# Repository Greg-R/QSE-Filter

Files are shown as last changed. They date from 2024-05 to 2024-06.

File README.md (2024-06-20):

# QSE-Filter Version 1.0

This is the PCB for the QSE-Filter module for the T41 "Software Defined Transceiver".
The PCB was designed using the open-source design tool Kicad 8.

The primary documentation for the T41 is the book "Digital Signal Processing and Software Defined Radio:
Theory and Construction of the T41-EP Software Defined Transceiver" by Albert Peter and Jack Purdum.
The book is available here:

<https://www.amazon.com/Digital-Signal-Processing-Software-Defined/dp/B0D25FV48C>

The goal of the QSE-Filter is to improve T41 transmitter fidelity.  Without using
this filter, the transmit output will contain spurious energy.  Using this simple filter
will resolve this problem.  The QSE-Filter module is designed to be the simplest
and lowest cost circuit to resolve this specific spurious energy problem.

The QSE-Filter is inserted between the output of the QSE module and the input of the
Power Amplifier.

Gerber files for PCB fabrication are included in the gerbers folder.
A PDF of the schematic (QSE-Filter.pdf) is included for quick viewing of the circuit design.

A look at the schematic:

<https://github.com/Greg-R/QSE-Filter/blob/main/QSE-Filter.pdf>

## Video Illustration of the Spurious Problem

This video shows why it is necessary to have a filter on the output of the QSE:

<https://drive.google.com/file/d/18EVahQOBdGZIAjiurM7DPEM1uzlL1K75/view?usp=drive_link>

### Hardware Modifications

A new ribbon cable is required.  The original T41 has a 10-wire cable which connects the Main board module to the Low-Pass
Filter module.  Since the QSE-Filter shares the same control signals, a new ribbon cable is required which routes from the
Main board to the QSE-Filter, and then to the Low-Pass module.  This type of cable is very easy to build and can be
completed in five minutes or less.

A wire must be added to the Main board to supply 3.3 volts.  This wire should be soldered to the back side of the Main
board from pin 8 of the "Bands" connector to a convenient source of 3.3 volts.  Looking at my modified Main board:

<https://drive.google.com/file/d/1hGLFVzCbjHw2UNAi1ffdGSL7jEQ02EJ3/view?usp=drive_link>

The green wire in the upper right area of the Main board routes 3.3 volts to the QSE-Filter via the ribbon cable.

There is no modification required to the software.

### PCB Layout

The PCB layout was completed using Kicad version 8.  This is an open-source tool, unlike the "Dip Trace" commercial product used
to design the V010 and other T41 boards.

The prototype PCBs were fabricated by PCBWay at a cost of US$1.00 each.  Shipping was about US$25.00 for quantity 5 boards.

## Bill Of Material (BOM)

A public Digikey BOM is here:

<https://www.digikey.com/en/mylists/list/BP824NCB5P>

The toroids are not included in the above BOM.  The T-37-6 (quantity 6) and T-37-17 (quantity 4) may be ordered from:

<https://kitsandparts.com/>

## Build Tips

In general, QSE-Filter is easy to build if you have experience with surface-mount components.  There are a few items to be aware of
to avoid build errors.

### SOT Devices

This circuit uses a lot of SOT devices!  These are generally well behaved when using a hot-air soldering station.  Be careful to not
use too much solder on the pads.  I had one short-circuit underneath one of the switches which caused high filter loss.  A little
bit of probing with a DVM revealed the short, and once the short was cleared the circuit worked as expected.

### Toroids

This is what I consider the most difficult part of building the filter.  Toroid winding!
The toroid part numbers, wire gauge, and number of turns are shown on the schematic.

Try to space the windings evenly around the circumference of the toroid.  However, the will be a gap in the windings
at the wire ends.

The toroids are "surface mounted", meaning that there is a rectangular pad for soldering the wire end.  I find this much
easier to deal with than using through-holes, as soldering and re-soldering is much easier.  Why resoldering?  Because
it may be necessary to add or remove a turn to get the frequency response lined up just right.  Hopefully not, however,
there are tolerances associated with both the capacitors and the toroids.  The inductance will be a function of the toroid
permeability, the number of turns, and also how you wound it.  The frequency responses of the filters are designed to have
margin, so hopefully all will line up and the frequency response of the filters will achieve the goal of a clean transmit
spectrum.

I have recommended using AWG#28 for the 80, 40, and 20 meter coils, and AWG#27 for the 15 and 10 meter coils.
However, AWG#27 will probably work for all of the coils.  I have not tried this yet.

### 3D Printed Bracket

The QSE Filter uses a custom 3D printed bracket.  I have a repository with many files for T41 parts including the QSE Filter bracket:

<https://github.com/Greg-R/SDT_Case_KF5N>

### Bottom Side Parts

There are many parts on the bottom side.  These should be soldered after the top-side SMDs.  I was able to use a hot air gun without any of the top-side components desoldering.

Solder the 16 pin connector and the SMA connectors last.

### SMA Connectors

Take a good look at the placement of the board in your T41 radio.  You will want the SMA connectors of the QSE-Filter in the orientation for
easy coaxial cable routing.  0 or 90 degree connectors are available (90 degree parts are on the BOM).  Also, you may choose to put the SMAs on one side or the other for optimal cable routing.

### High Resolution Photos of QSE-Filter

Links to photos of a fully constructed QSE-Filter follow.

<https://drive.google.com/file/d/1yyc1hCo5w5VuUIPOOLpDOkUyore53iXK/view?usp=sharing>

<https://drive.google.com/file/d/1FSENao2-BARYMb8nm4-y8Q7-AhVFKQNp/view?usp=sharing>

## Example Measured Filter Response 10 Meters

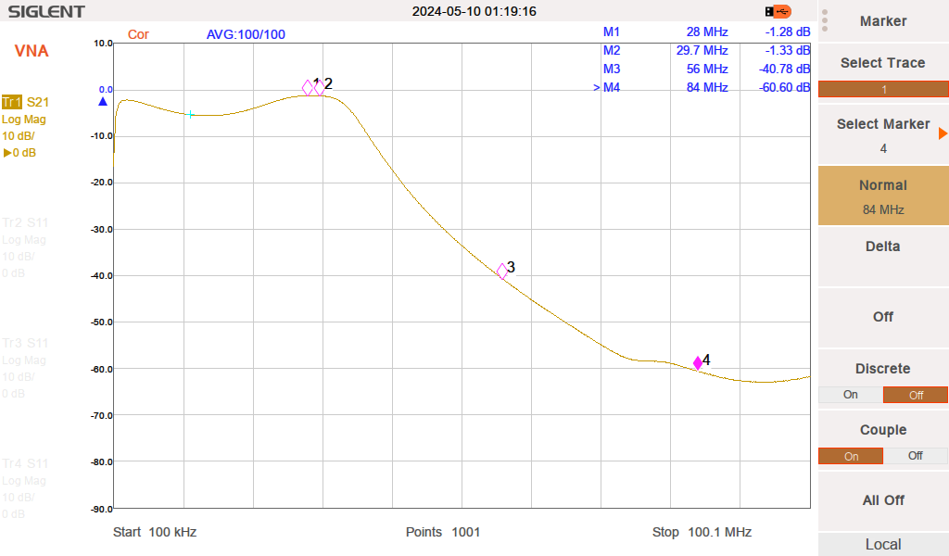
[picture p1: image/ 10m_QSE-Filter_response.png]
10 meter filter frequency response


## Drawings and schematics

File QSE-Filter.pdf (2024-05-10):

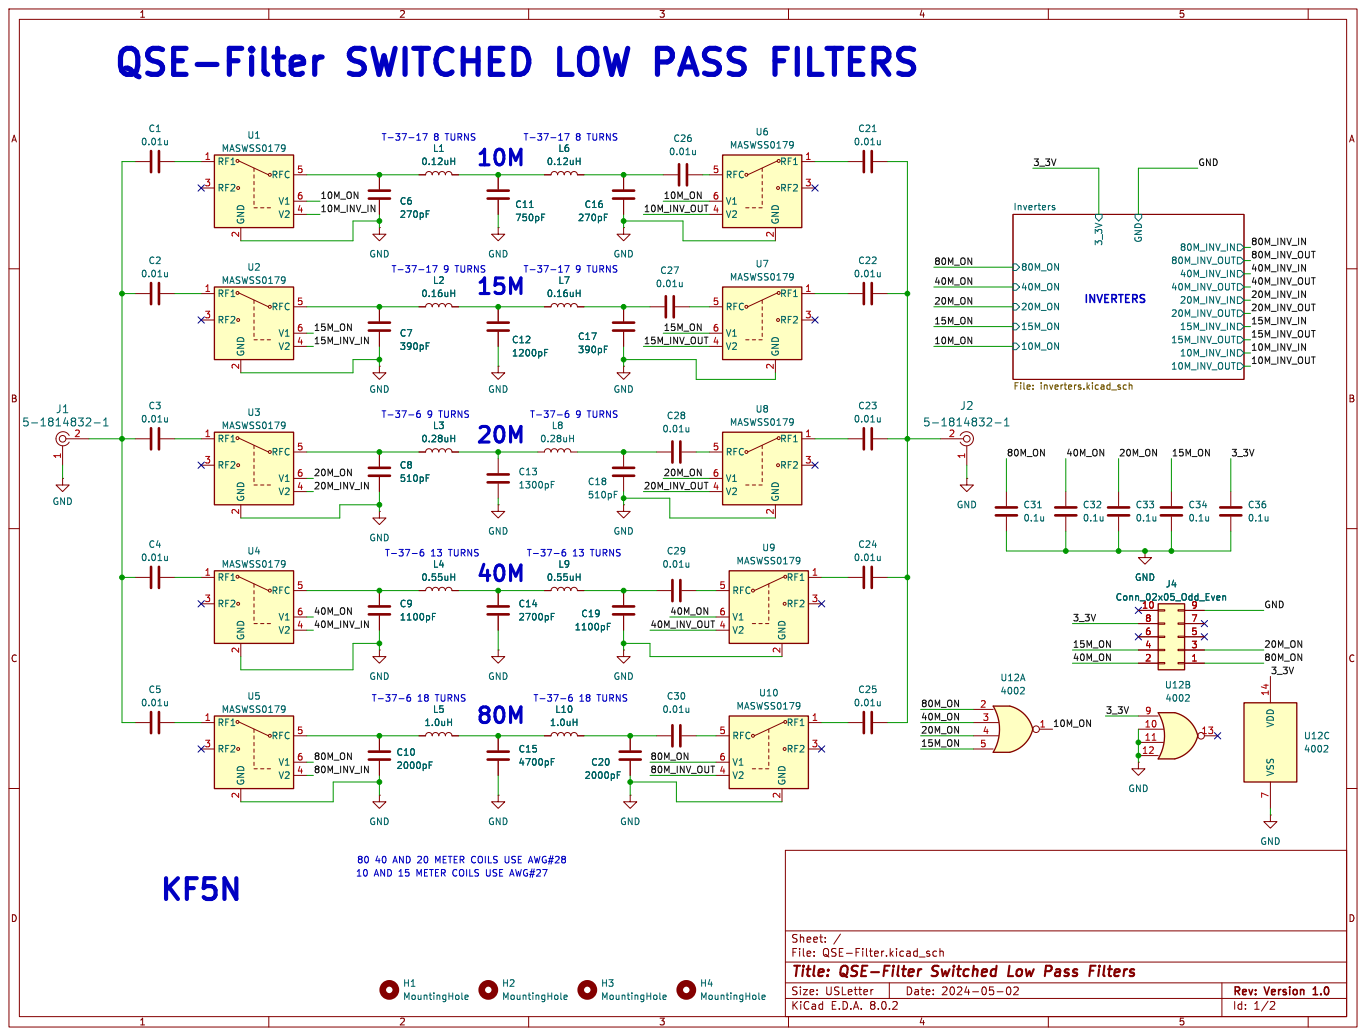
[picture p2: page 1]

80 40 AND 20 METER COILS USE AWG#28

File: QSE-Filter.kicad_sch Sheet: /

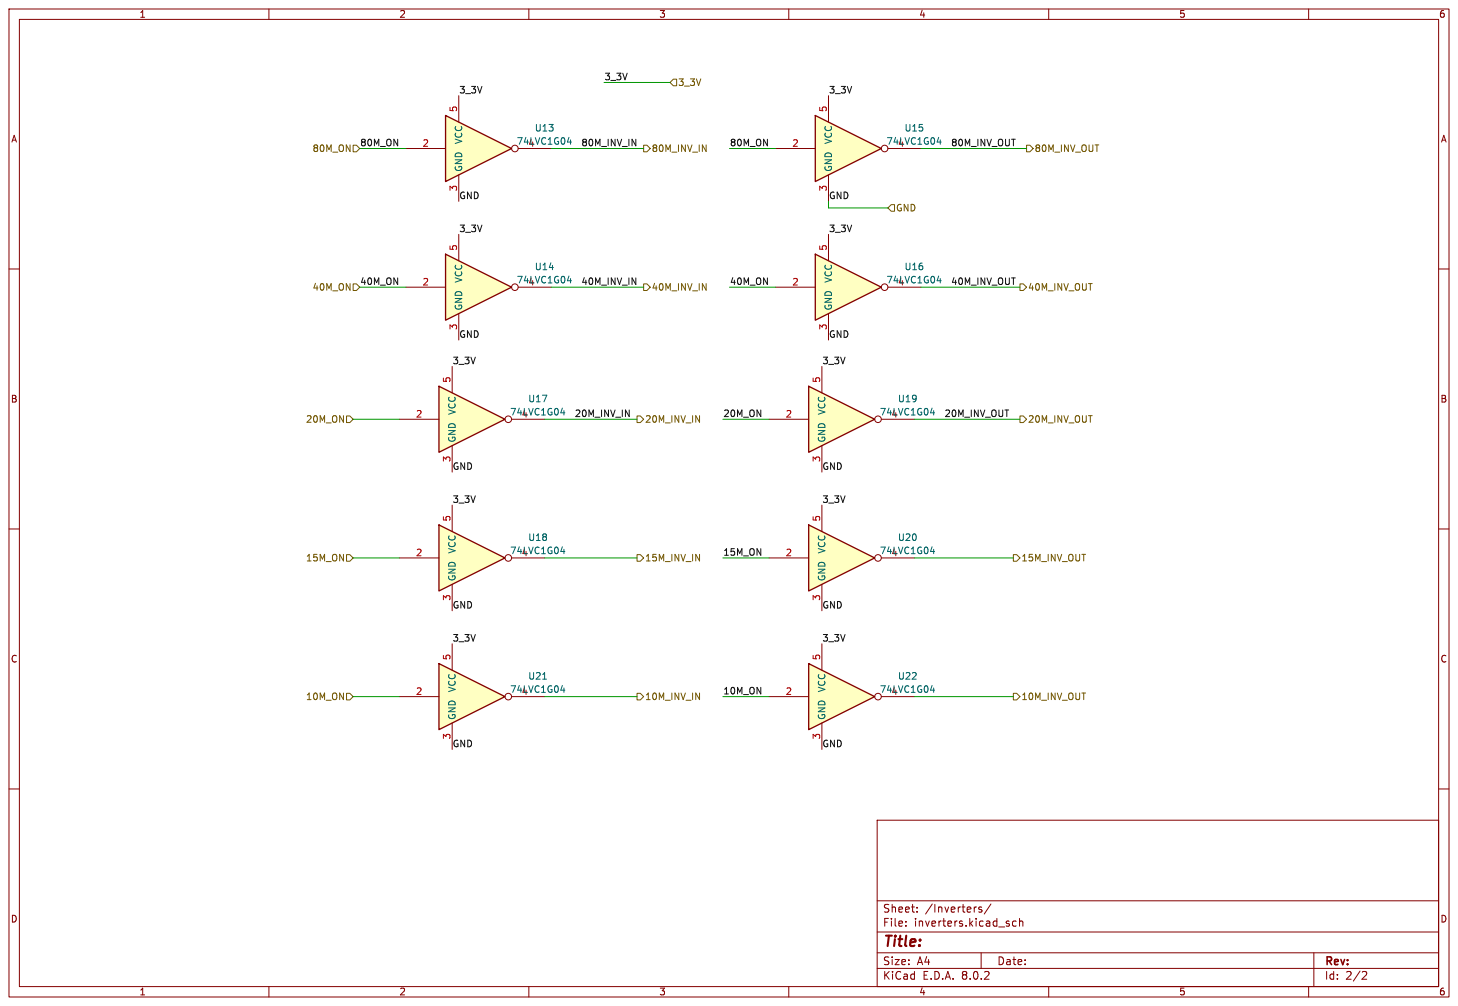
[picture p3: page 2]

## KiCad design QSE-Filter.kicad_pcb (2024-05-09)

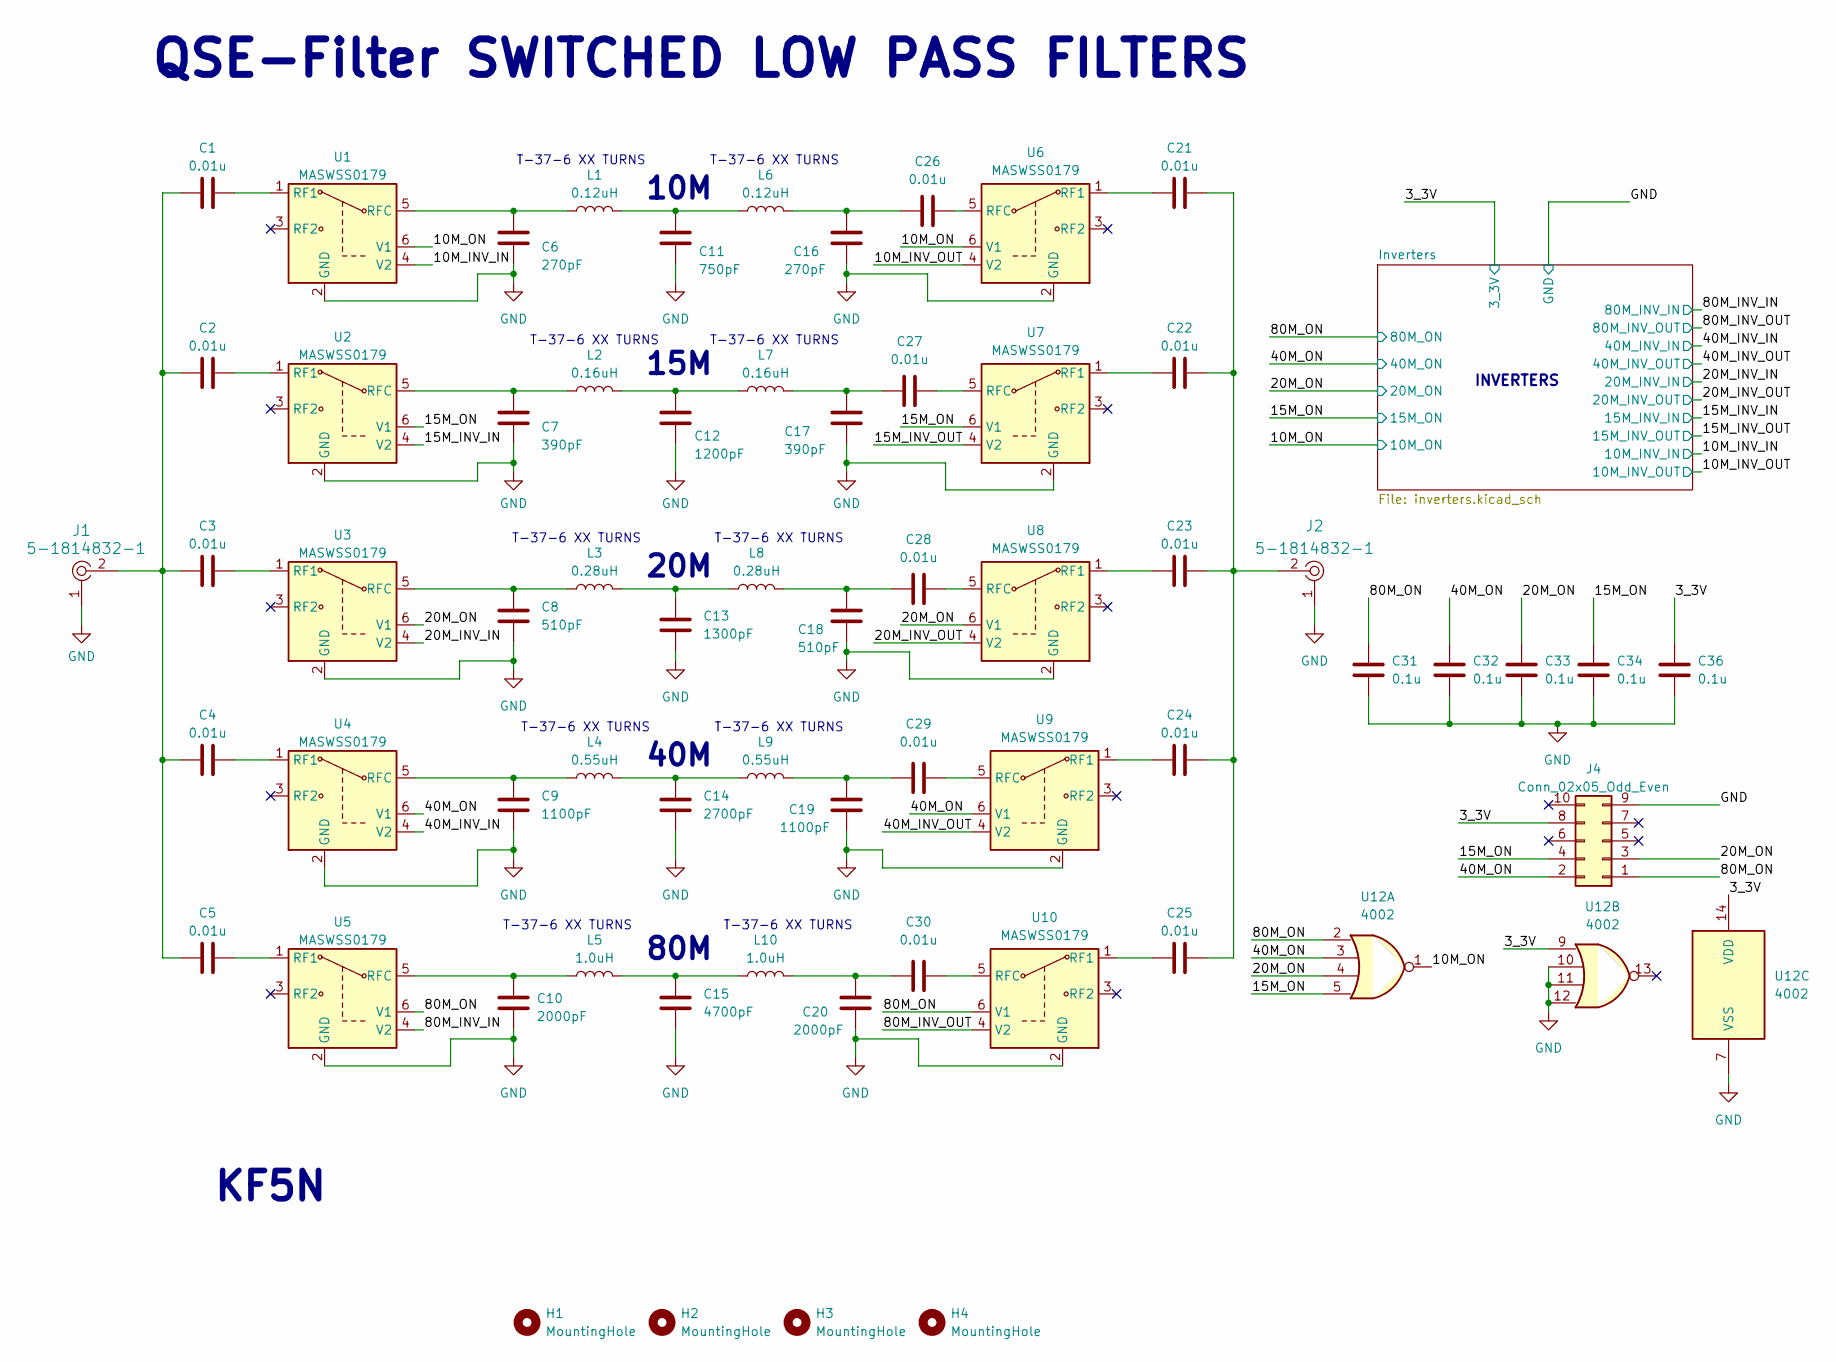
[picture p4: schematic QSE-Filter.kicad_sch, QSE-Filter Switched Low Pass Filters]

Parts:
C1, C2, C3, C4, C5, C21, C22, C23, C24, C25, C26, C27, C28, C29, C30: 0.01u; C_1206_3216Metric
C6, C16: 270pF; C_1206_3216Metric
C7, C17: 390pF; C_1206_3216Metric
C8, C18: 510pF; C_1206_3216Metric
C9, C19: 1100pF; C_1206_3216Metric
C10, C20: 2000pF; C_1206_3216Metric
C11: 750pF; C_1206_3216Metric
C12: 1200pF; C_1206_3216Metric
C13: 1300pF; C_1206_3216Metric
C14: 2700pF; C_1206_3216Metric
C15: 4700pF; C_1206_3216Metric
C31, C32, C33, C34, C36: 0.1u; C_1206_3216Metric
H1, H2, H3, H4: MountingHole; MountingHole_3.2mm_M3
J1, J2: 5-1814832-1; RF_SMA_Vertical_5-1814832-1; MPN 5-1814832-1; Digi-Key_PN A97594-ND
J4: Conn_02x05_Odd_Even; IDC-Header_2x05_P2.54mm_Vertical
L1, L6: 0.12uH; Toroid_SMD
L2, L7: 0.16uH; Toroid_SMD
L3, L8: 0.28uH; Toroid_SMD
L4, L9: 0.55uH; Toroid_SMD
L5, L10: 1.0uH; Toroid_SMD
U1, U2, U3, U4, U5, U6, U7, U8, U9, U10: MASWSS0179; SOT-23-6
U12: 4002; SOIC-14_3.9x8.7mm_P1.27mm

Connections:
/3_3V: C36.2, J4.8, U12.9, U12.14 (VDD); also elsewhere on the board
/10M_INV_IN: U1.4 (V2); also elsewhere on the board
/10M_INV_OUT: U6.4 (V2); also elsewhere on the board
/10M_ON: U1.6 (V1), U6.6 (V1), U12.1; also elsewhere on the board
/15M_INV_IN: U2.4 (V2); also elsewhere on the board
/15M_INV_OUT: U7.4 (V2); also elsewhere on the board
/15M_ON: C34.2, J4.4, U2.6 (V1), U7.6 (V1), U12.5; also elsewhere on the board
/20M_INV_IN: U3.4 (V2); also elsewhere on the board
/20M_INV_OUT: U8.4 (V2); also elsewhere on the board
/20M_ON: C33.2, J4.3, U3.6 (V1), U8.6 (V1), U12.4; also elsewhere on the board
/40M_INV_IN: U4.4 (V2); also elsewhere on the board
/40M_INV_OUT: U9.4 (V2); also elsewhere on the board
/40M_ON: C32.2, J4.2, U4.6 (V1), U9.6 (V1), U12.3; also elsewhere on the board
/80M_INV_IN: U5.4 (V2); also elsewhere on the board
/80M_INV_OUT: U10.4 (V2); also elsewhere on the board
/80M_ON: C31.2, J4.1, U5.6 (V1), U10.6 (V1), U12.2; also elsewhere on the board
GND: C6.2, C7.2, C8.2, C9.2, C10.2, C11.2, C12.2, C13.2, C14.2, C15.2, C16.2, C17.2, C18.2, C19.2, C20.2, C31.1, C32.1, C33.1, C34.1, C36.1, J1.1, J2.1, J4.9, U1.2 (GND), U2.2 (GND), U3.2 (GND), U4.2 (GND), U5.2 (GND), U6.2 (GND), U7.2 (GND), U8.2 (GND), U9.2 (GND), U10.2 (GND), U12.7 (VSS), U12.10, U12.11, U12.12; also elsewhere on the board
unnamed: C1.1, C2.1, C3.1, C4.1, C5.1, J1.2
unnamed: C11.1, L1.2, L6.1
unnamed: C12.1, L2.2, L7.1
unnamed: C13.1, L3.2, L8.1
unnamed: C14.1, L4.2, L9.1
unnamed: C15.1, L5.2, L10.1
unnamed: C16.1, C26.1, L6.2
unnamed: C17.1, C27.1, L7.2
unnamed: C18.1, C28.1, L8.2
unnamed: C19.1, C29.1, L9.2
unnamed: C20.1, C30.1, L10.2
unnamed: C21.2, C22.2, C23.2, C24.2, C25.2, J2.2
unnamed: C1.2, U1.1 (RF1)
unnamed: C6.1, L1.1, U1.5 (RFC)
unnamed: C2.2, U2.1 (RF1)
unnamed: C7.1, L2.1, U2.5 (RFC)
unnamed: C3.2, U3.1 (RF1)
unnamed: C8.1, L3.1, U3.5 (RFC)
unnamed: C4.2, U4.1 (RF1)
unnamed: C9.1, L4.1, U4.5 (RFC)
unnamed: C5.2, U5.1 (RF1)
unnamed: C10.1, L5.1, U5.5 (RFC)
unnamed: C21.1, U6.1 (RF1)
unnamed: C26.2, U6.5 (RFC)
unnamed: C22.1, U7.1 (RF1)
unnamed: C27.2, U7.5 (RFC)
unnamed: C23.1, U8.1 (RF1)
unnamed: C28.2, U8.5 (RFC)
unnamed: C24.1, U9.1 (RF1)
unnamed: C29.2, U9.5 (RFC)
unnamed: C25.1, U10.1 (RF1)
unnamed: C30.2, U10.5 (RFC)

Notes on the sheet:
T-37-6 XX TURNS
INVERTERS
40M
QSE-Filter SWITCHED LOW PASS FILTERS
15M
80M
20M
10M
KF5N

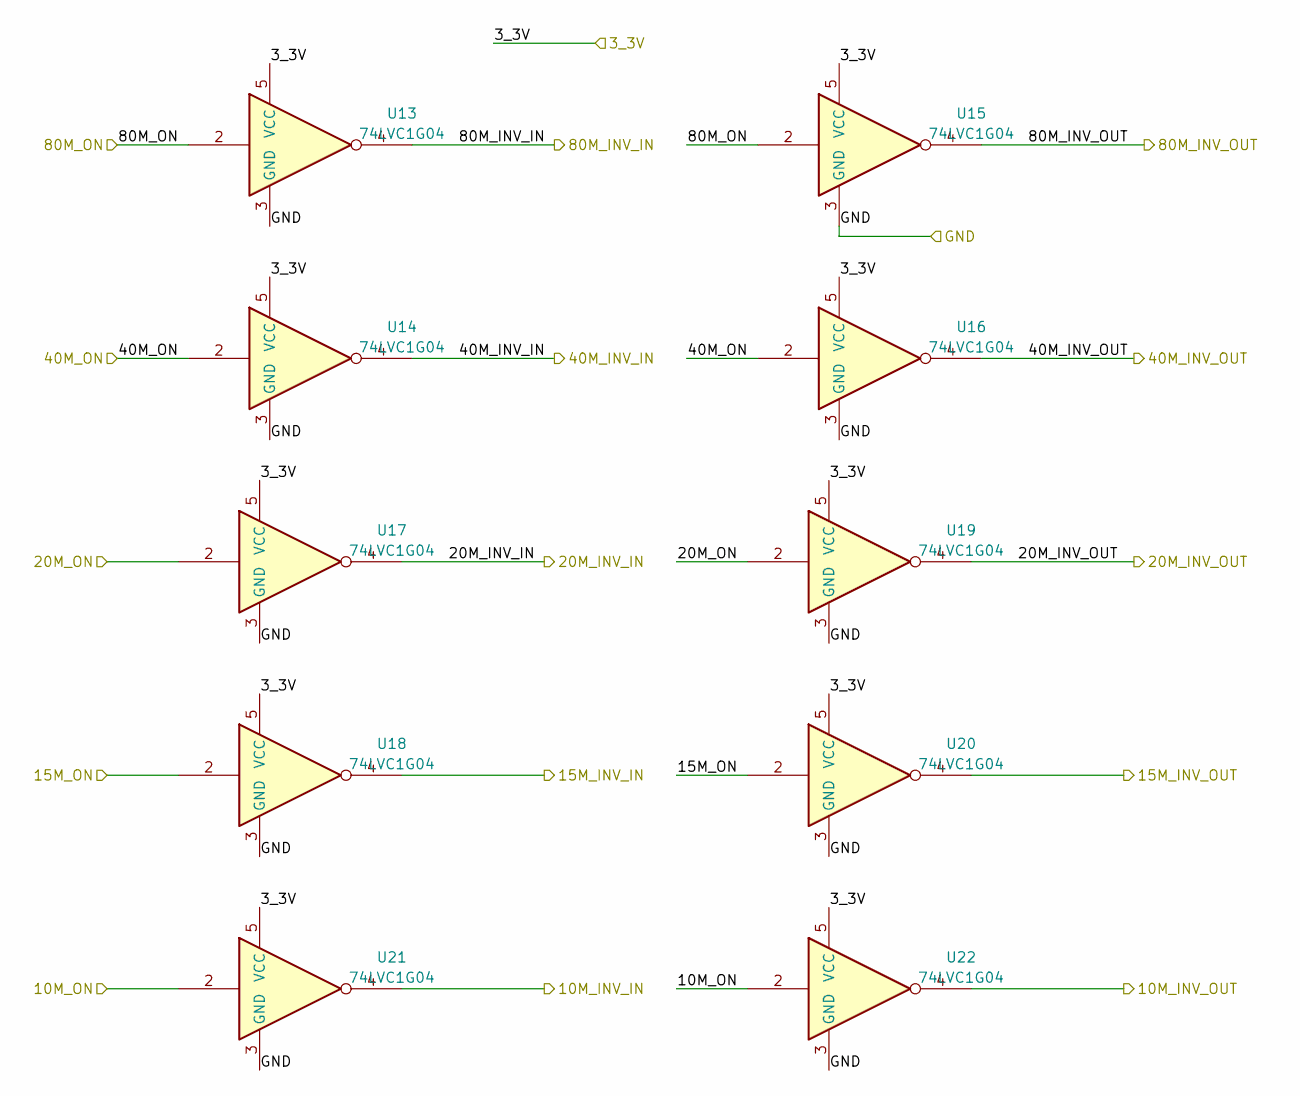
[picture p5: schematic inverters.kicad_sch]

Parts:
U13, U14, U15, U16, U17, U18, U19, U20, U21, U22: 74LVC1G04; SOT-353

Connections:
/3_3V: U13.5 (VCC), U14.5 (VCC), U15.5 (VCC), U16.5 (VCC), U17.5 (VCC), U18.5 (VCC), U19.5 (VCC), U20.5 (VCC), U21.5 (VCC), U22.5 (VCC); also elsewhere on the board
/10M_INV_IN: U21.4; also elsewhere on the board
/10M_INV_OUT: U22.4; also elsewhere on the board
/10M_ON: U21.2, U22.2; also elsewhere on the board
/15M_INV_IN: U18.4; also elsewhere on the board
/15M_INV_OUT: U20.4; also elsewhere on the board
/15M_ON: U18.2, U20.2; also elsewhere on the board
/20M_INV_IN: U17.4; also elsewhere on the board
/20M_INV_OUT: U19.4; also elsewhere on the board
/20M_ON: U17.2, U19.2; also elsewhere on the board
/40M_INV_IN: U14.4; also elsewhere on the board
/40M_INV_OUT: U16.4; also elsewhere on the board
/40M_ON: U14.2, U16.2; also elsewhere on the board
/80M_INV_IN: U13.4; also elsewhere on the board
/80M_INV_OUT: U15.4; also elsewhere on the board
/80M_ON: U13.2, U15.2; also elsewhere on the board
GND: U13.3 (GND), U14.3 (GND), U15.3 (GND), U16.3 (GND), U17.3 (GND), U18.3 (GND), U19.3 (GND), U20.3 (GND), U21.3 (GND), U22.3 (GND); also elsewhere on the board

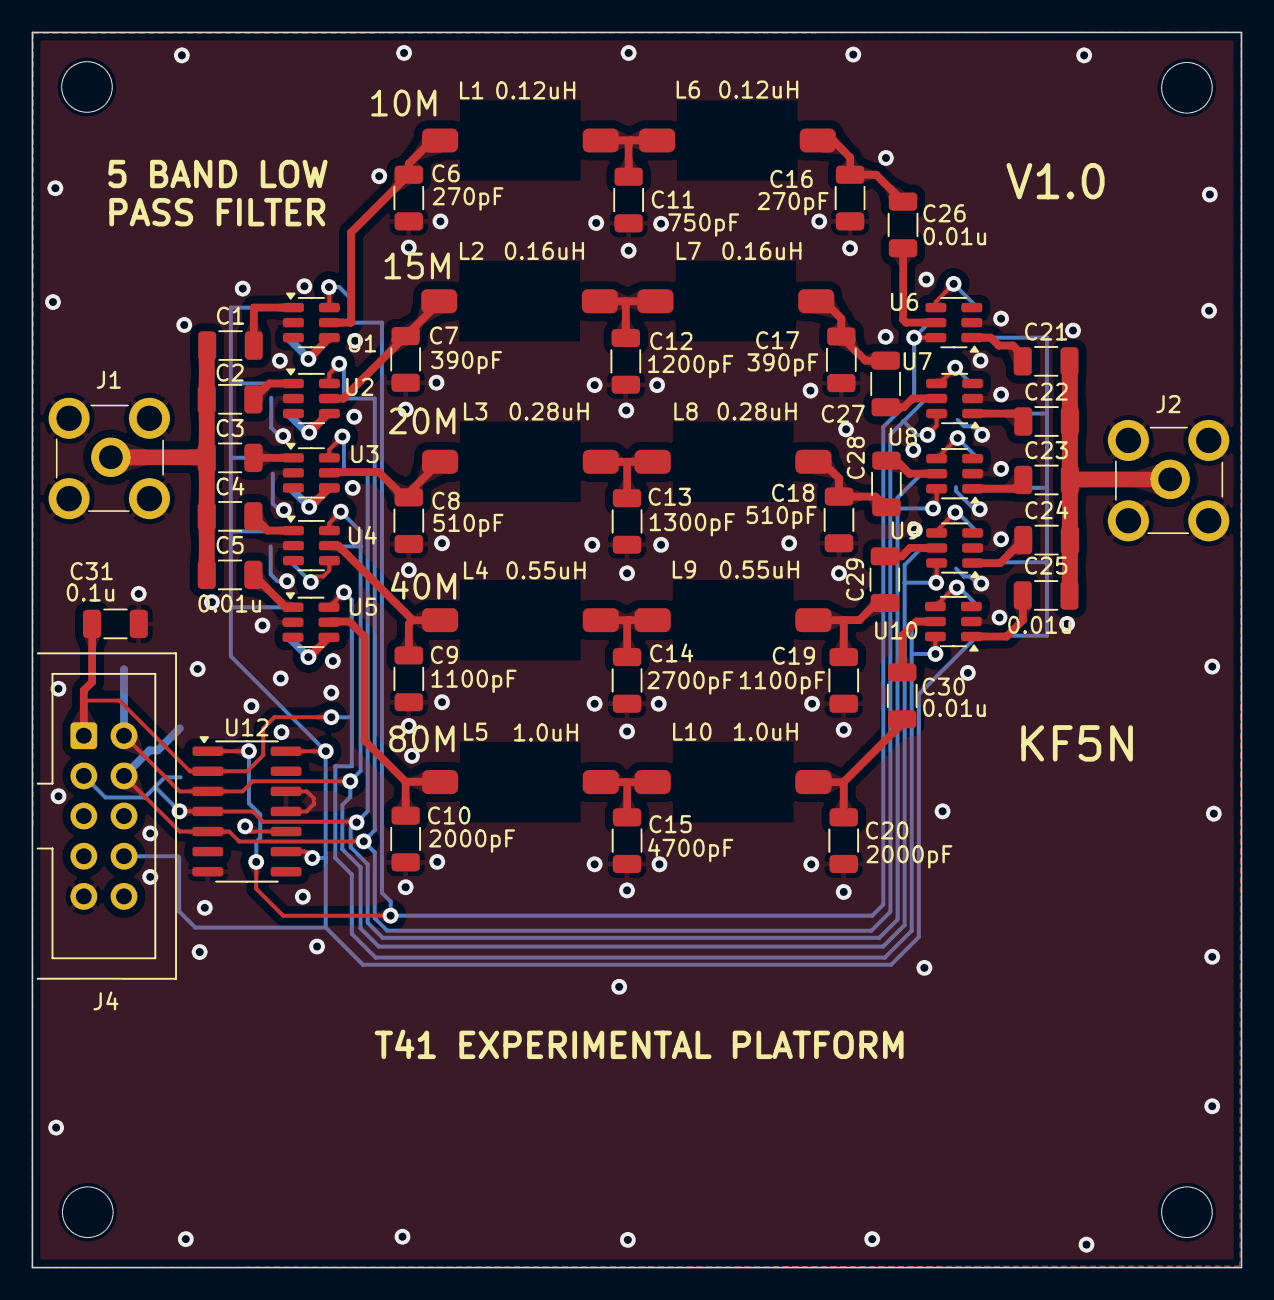
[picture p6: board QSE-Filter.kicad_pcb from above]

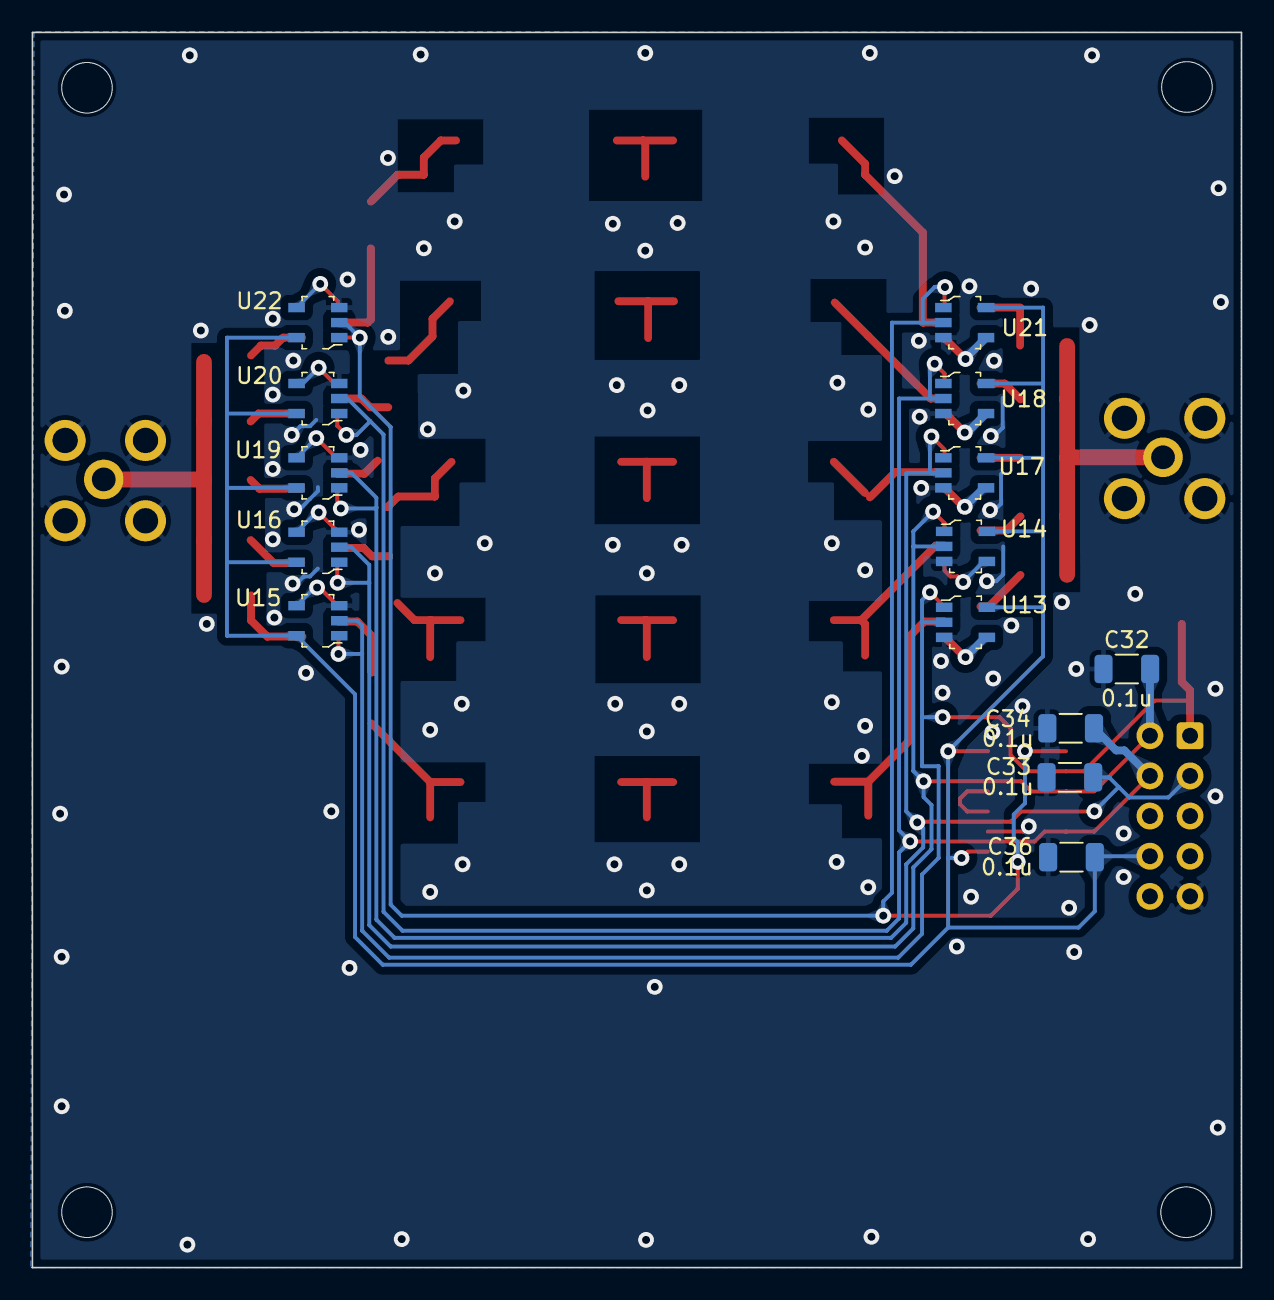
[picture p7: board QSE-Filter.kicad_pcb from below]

Board: 2 copper layers, 76.5 x 78.1 mm, 73 parts (14 on the bottom side), 49 nets.

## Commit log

2024-05-09 Initial commit.
    [QSE-Filter-B_Cu.gbl, QSE-Filter-B_Mask.gbs, QSE-Filter-B_Silkscreen.gbo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]
2024-05-09 Updated schematic with toroid winding information.
    [QSE-Filter.kicad_sch, inverters.kicad_sch]
2024-05-10 Added link to revised schematic.
2024-05-11 Added comment on wire added to Main board.
2024-06-20 Updated comment on bracket.
